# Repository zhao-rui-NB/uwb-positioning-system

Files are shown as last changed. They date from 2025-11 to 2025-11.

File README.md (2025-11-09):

# uwb-positioning-system

## 專案總覽
這個儀專案整合了 **ESP32+DWM1000 韌體**、**對應硬體設計** 與 **Python 可視化 Host App**，目標是建置可以在室內部署的 UWB 定位系統。韌體負責超寬頻量測與序列埠通訊、硬體提供可量產的電路與機構、Host App 則把距離資料轉為即時 2D/3D 位置並提供後續交接時最重要的溝通介面。

## 目錄導覽
- `firmware/`：PlatformIO 專案，產生可燒錄到 ESP32-DWM1000 節點的韌體。
- `hardware/`：ESP32_DWM1000_V1 的 PCB、BOM、殼體與 3D 檔案。
- `host_app/`：Python + PyQt6 介面，透過序列埠操控節點、做距離採樣與定位演算法。

---

## Firmware（`firmware/ESP32-DWM1000`）
1. **建置環境**
   - 安裝 [PlatformIO CLI](https://platformio.org/) 或 VS Code + PlatformIO IDE。
   - 需要 ESP32 USB 驅動與 115200 bps 序列埠。
2. **編譯與燒錄**
   - `cd firmware/ESP32-DWM1000`
   - 編譯：`pio run`
   - 燒錄：`pio run -t upload`（可用 `-t monitor` 觀察訊息）
3. **節點角色**
   - `uwb_node_id` 由程式內部邏輯或使用者命令設定，Anchor 建議使用 `0xFF00` 起跳，Tag 使用 `0x0000` 起跳。
4. **主控指令**
   - 序列埠接受 ASCII 指令，換行分隔：
     - `ping <node_id>`：請 <node_id> 回報系統狀態與電壓。
     - `trigger <initiator_id> <responder_id>`：觸發 initiator 與 responder 間的 TWR 量測。
   - 回傳為單行 JSON，事件種類：
     - `{"event":"ping_resp","node_id":...,"system_state":...,"voltage_mv":...}`
     - `{"event":"range_report","node_a_id":...,"node_b_id":...,"distance_m":...,"rssi_dbm":...}`
     - `{"event":"range_final", ...}`（最終距離結果）。

---

## Hardware（`hardware/esp32_DWM1000_V1`）
1. **PCB 製造**
   - `pcb/Gerber_esp32_DWM1000_V1_2025-10-20.zip` 交給板廠即可生產。
   - `pcb/BOM_esp32_DWM1000_*.xlsx` 提供物料代號與封裝，搭配 `InteractiveBOM_*.html` 可快速查料。
   - `pcb/SCH_Schematic1_*.pdf` 與 `3D_*.step` 提供電路與 3D 參考。
2. **外殼/治具**
   - `shell/外殼.stl`、`shell/ESP32_DWM1000_外殼2 v26.f3z` 可 3D 列印或交由 Fusion 360 編修。
   - `shell/側按鍵*.stl` 與 `shell/壓克力.dxf` 用於按鍵、壓克力面板。

---

## Host App（`host_app/`）
Host App，負責和裝置溝通、資料視覺化與定位演算。

### 環境設定
1. 使用 Python 3.11（建議建立虛擬環境 `python -m venv venv` 並啟用）。
2. 安裝套件：`pip install -r requirements.txt`。
3. 依需求編輯 `config.json`：
   - `anchors`: `id`（與韌體相同的 16-bit ID）、`pos`（[x,y,z]，單位公尺）、`enable`。
   - `tags`: `id` 與 `z`、`enable`。Z 可固定高度以減化三角定位。

### 執行與操作
1. `python UWB_DEMO_APP.py` 開啟 PyQt6 介面。
2. 於左下輸入序列埠（例如 `COM7`）與鮑率（預設 115200），按「Connect」即可建立 `SerialWorker` 執行緒。
3. 程式啟動時計時器每 `update_position` 週期會：
   - 讀取 `config.json` 中啟用的 Tag、Anchor 列表。
   - 透過 `UWBController.trigger_multiple(tag_id, anchor_ids)` 走訪所有 anchor。
   - 每次 `trigger` 會送出 `trigger <tag> <anchor>`，等待 JSON 的 `range_report/range_final`。
   - 同時可使用 `ping_single`/`ping_all` 按鈕，送出 `ping <node>` 取得電壓與狀態。
4. `TrilaterationSolver3D` 會把有效距離組合轉為 (x,y,z)，再由 `UWBKalmanFilter` 平滑並顯示在平面圖與 RSSI 表格。
5. 介面支援：
   - 拖曳 Anchor 位置（`DraggableScatterPlotItem`），並可儲存為新的 `config.json`。
   - 清除 Tag 路徑、顯示即時 RSSI/距離列表、手動載入/儲存多組配置。

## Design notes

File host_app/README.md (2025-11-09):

# Host App 指南

## 檔案對照
| 檔案 | 功能摘要 |
| --- | --- |
| `SerialWorker.py` | 底層串列通訊執行緒，維持 `Serial` 連線、將裝置回傳的 JSON 事件塞入 queue，並提供 `send_command`/`read_response` API。 |
| `UWBController.py` | 封裝序列指令集合，包含 `ping`、`trigger`、`trigger_multiple` 等方法，並以資料類別 (`RangeResponse`, `PingResponse`) 回傳解析後結果。 |
| `TrilaterationSolver3D.py` | 以多個 Anchor 座標與距離解三點/多點定位的演算法，支援固定 Z 的 3D 求解並提供校正/排序工具。 |
| `UWBKalmanFilter.py` | 對定位結果進行單點 Kalman 濾波，降低量測噪訊與跳動。每個 Tag 會各自維持一個濾波器實例。 |
| `UWB_DEMO_APP.py` | PyQt6 主程式：控制介面、Anchor/Tag 管理、即時圖表、RSSI 表格、手動載入/儲存 `config.json`，並定期呼叫控制器量測距離。 |
| `config.json` | Anchor 與 Tag 的 ID、座標、啟用狀態與預設高度設定，GUI 讀取後即能還原場地配置。拖曳 Anchor 或儲存設定時也會覆寫這個檔案。 |
| `requirements.txt` | Host App 依賴的 Python 套件列表 (PyQt6、pyserial、pyqtgraph、numpy…)，交接時可直接 `pip install -r requirements.txt`。 |

# 🛰️ UWB 定位系統上位機 (PyQt6)

## 📋 系統概述
這是一個使用 **PyQt6 + pyqtgraph** 開發的上位機應用程式，用於顯示與控制 **UWB（超寬頻）定位系統**。  
支援多個 Anchor（基站）與 Tag（標籤）節點，能透過串口通訊進行距離量測、定位與地圖可視化操作。

---

## ⚙️ 功能總覽

### 🔌 串口連線控制
- 指定連線埠 (`COM`) 與鮑率 (`Baudrate`)。
- 支援：
  - **Connect**：連線到指定序列埠。
  - **Disconnect**：中斷連線。
  - **Ping**：測試節點電壓與回應狀態。

---

### 💾 設定管理（Save / Load）
- 可儲存與載入 **Anchor** 和 **Tag** 配置：
  - `Save`：儲存目前配置為 `config.json`。
  - `Load`：從檔案中載入設定。
- 啟動時自動讀取 `config.json`（若存在）。
- 設定檔內容包括：
  - Anchor ID、座標 (X/Y/Z)、啟用狀態。
  - Tag ID、高度 Z、啟用狀態。

---

### 📍 Anchor 管理
- 新增 / 移除 Anchor 節點。
- 可編輯每個 Anchor 的：
  - ID（16 進位顯示，如 `0xFF00`）
  - 座標 X / Y / Z。
- 支援啟用 / 停用。
- 可在地圖上**拖曳** Anchor 點直接修改位置（即時更新表格）。

---

### 🎯 Tag 管理
- 新增 / 移除 Tag。
- 可設定：
  - Tag ID。
  - 固定高度 Z。
- 支援啟用 / 停用。
- 顯示：
  - Tag 即時位置。
  - 移動軌跡（含濾波平滑）。

---

### 📶 RSSI 與距離顯示
- 以表格顯示：
  - Tag ID。
  - Anchor ID。
  - 距離 (m)。
  - RSSI (dBm)。
- 定期更新，顯示最新量測結果。

---

### 🔧 Anchor 自動校正 (Calibration)
- 啟用兩個以上的 Anchor 可進行自動校正。
- 自動測距所有 Anchor 配對。
- 使用 **多維尺度分析 (MDS)** 計算相對位置。
- 自動更新 Anchor 座標與地圖。
- 僅支持2D校正（Z軸固定,需將Anchor放置於同一平面）。

---

### 🗺️ 地圖繪製與互動
- 即時顯示：
  - Anchor（紅色三角形）。
  - Tag（彩色圓點）。
  - Tag 移動路徑。
- 使用 **pyqtgraph**：
  - 鎖定等比例座標。
  - 顯示格線與軸標籤 (X/Y)。
  - Anchor 點可拖曳以修改位置。

---

### 🧹 其他輔助功能
- `Clear Paths`：清除所有 Tag 的歷史軌跡。
- 狀態列顯示系統狀態、連線資訊與錯誤提示。
- 自動檢查 Anchor 數量不足時顯示警告。

---

## 🖥️ 操作介面說明
- 左側控制面板：
  - 系統控制、連線設定、Ping 測試、Anchor/Tag 管理、RSSI 監控與校正。
- 右側地圖區：
  - 即時顯示 Anchor、Tag、軌跡。
  - 可互動拖曳 Anchor 點設定座標。

---

## 🚀 執行方式

```bash
# 建立虛擬環境
python -m venv venv
source venv/bin/activate     # (Windows 用 venv\Scripts\activate)

# 安裝依賴
pip install -r requirements.txt

# 執行主程式
python UWB_DEMO_APP.py
```

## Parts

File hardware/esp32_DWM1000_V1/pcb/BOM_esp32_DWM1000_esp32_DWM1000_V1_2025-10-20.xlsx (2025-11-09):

No. | Quantity | Comment | Designator | Footprint | Value | Manufacturer Part | Manufacturer | Supplier Part | Supplier
1 | 2 | 1uF | C1,C2 | C0805 | 1uF
2 | 9 | 0.1uF | C3,C4,C5,C6,C7,C8,C13,C14,C15 | C0805 | 0.1uF
3 | 4 | 10uF | C9,C10,C11,C12 | C0805 | 10uF
4 | 1 | X6511FRS-04-C85D30 | CN1 | HDR-SMD_4P-P2.54-H-F |  | X6511FRS-04-C85D30 | XKB Connection(中国星坤) | C5142237 | LCSC
5 | 1 | MBR230LSFT1G | D1 | SOD-123FL_L2.7-W1.8-LS3.8-RD |  | MBR230LSFT1G | onsemi(安森美) | C126673 | LCSC
6 | 1 | WAFER-PH2.0-2PWB | H1 | CONN-SMD_2P-P2.00_XUNPU_WAFER-PH2.0-2PWB |  | WAFER-PH2.0-2PWB | XUNPU(讯普) | C3029440 | LCSC
7 | 2 | LED_0805-R | LED1,LED2 | LED0805-RD_GREEN
8 | 2 | S8050 | Q1,Q2 | SOT-23-3_L2.9-W1.3-P1.90-LS2.4-BR |  | S8050 |  | C139514 | LCSC
9 | 1 | AO3401 | Q3 | SOT-23-3_L2.9-W1.6-P1.90-LS2.8-BR |  | AO3401 | BLUE ROCKET(蓝箭) | C305433 | LCSC
10 | 5 | 10k | R1,R2,R5,R8,R9 | R0805 | 10k | SCR0805F10K | VO(翔胜) |  | LCSC
11 | 6 | 10k | R3,R4,R14,R16,R17,R18 | R0805 | 10k
12 | 1 | NC | R6 | R0805 | NC | SCR0805F10K | VO(翔胜) |  | LCSC
13 | 2 | 4.7k | R7,R11 | R0805 | 4.7k | SCR0805F10K | VO(翔胜) |  | LCSC
14 | 1 | 15k | R10 | R0805 | 15k | SCR0805F10K | VO(翔胜) |  | LCSC
15 | 1 | 240k | R12 | R0805 | 240k | SCR0805F10K | VO(翔胜) |  | LCSC
16 | 4 | 1k | R13,R15,R19,R23 | R0805 | 1k | SCR0805F10K | VO(翔胜) |  | LCSC
17 | 2 | 5.1k | R20,R21 | R0805 | 5.1k | SCR0805F10K | VO(翔胜) |  | LCSC
18 | 2 | 100k | R22,R25 | R0805 | 100k | SCR0805F10K | VO(翔胜) |  | LCSC
19 | 1 | 200k | R24 | R0805 | 200k | SCR0805F10K | VO(翔胜) |  | LCSC
20 | 4 | Screw-Hole-M3 | SCREW1,SCREW2,SCREW3,SCREW4 | Screw-Hole-M3
21 | 2 | HX-3x6x2.5-X SMD tact Switch | SW1,SW2 | SW-SMD_HX-3X6X2.5-X |  | HX-3x6x2.5-X SMD tact Switch | hanxia(韩下) | C49234125 | LCSC
22 | 3 | HX-3x6x3.5-CA-0.6-2.5N | SW3,SW4,SW5 | SW-SMD_HX-3X6X3.5-CA-0.6-2.5N |  | HX-3x6x3.5-CA-0.6-2.5N | hanxia(韩下) | C49234146 | LCSC
23 | 1 | MK-12C02-G020 | SW6 | SW-SMD_MK-12C02-G020 |  | MK-12C02-G020 | G-Switch(品赞) | C963206 | LCSC
24 | 1 | DWM1000 | U1 | WIRELM-TH_DWM1000 |  | DWM1000 | decaWave | C95238 | LCSC
25 | 1 | ESP32-WROOM-32-N4 | U2 | WIFIM-SMD_ESP32-WROOM-32-N4 |  | ESP32-WROOM-32-N4 | ESPRESSIF(乐鑫) | C82899 | LCSC
26 | 2 | X6511FRS-02-C85D30 | U3,U5 | HDR-SMD_2P-P2.54-H-F-L11.5 |  | X6511FRS-02-C85D30 | XKB Connection(中国星坤) | C5142235 | LCSC
27 | 1 | CH340C | U4 | SOP-16_L10.0-W3.9-P1.27-LS6.0-BL |  | CH340C | WCH(南京沁恒) | C84681 | LCSC
28 | 1 | SGM4056-6.8YPS8G/TR | U6 | SOIC-8_L4.9-W3.9-P1.27-LS6.0-BL-EP |  | SGM4056-6.8YPS8G/TR | SGMICRO(圣邦微) | C79687 | LCSC
29 | 1 | ME6217C33M5G | U7 | SOT-23-5_L3.0-W1.7-P0.95-LS2.8-BR |  | ME6217C33M5G | MICRONE(南京微盟) | C427602 | LCSC
30 | 1 | TYPEC-304-ACP16 | USB1 | USB-C-SMD_TYPE-C-16P-1 |  | TYPEC-304-ACP16 | XUNPU(讯普) | C2982555 | LCSC

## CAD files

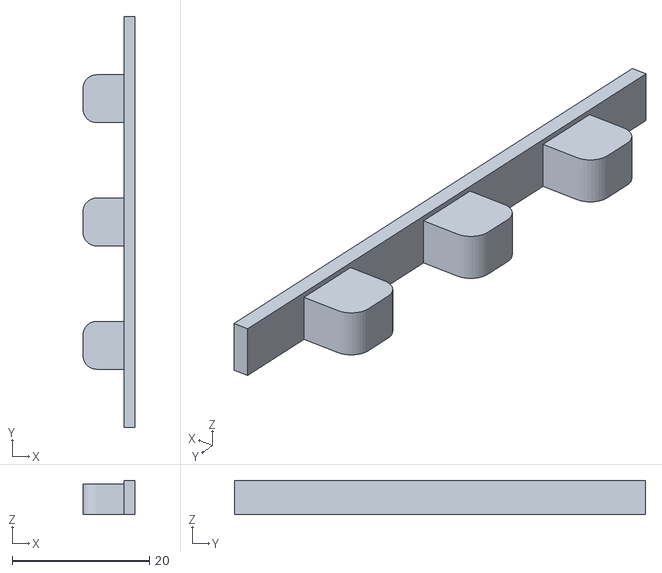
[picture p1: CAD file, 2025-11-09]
hardware/esp32_DWM1000_V1/shell/側按鍵.stl
7.60 x 60.0 x 5.00

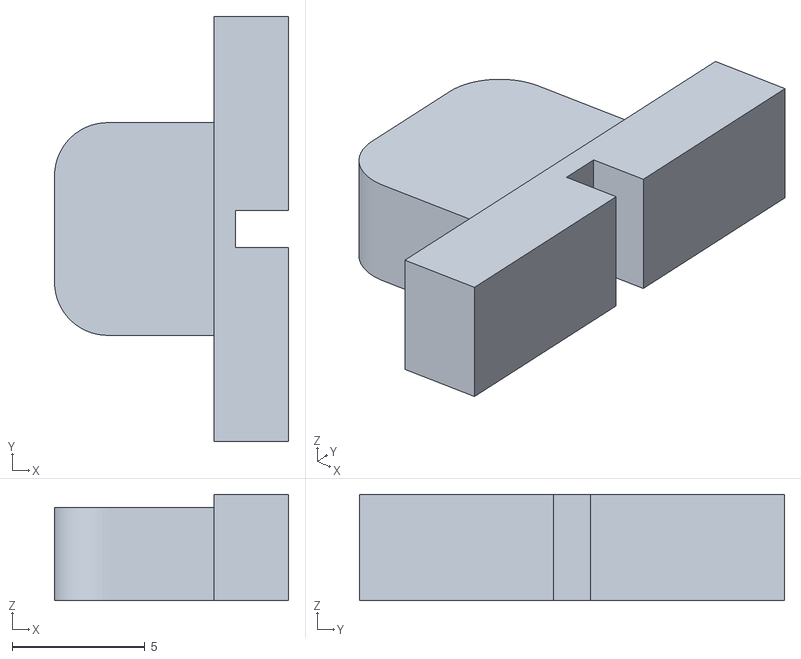
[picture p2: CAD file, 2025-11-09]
hardware/esp32_DWM1000_V1/shell/側開關.stl
8.80 x 16.0 x 4.00

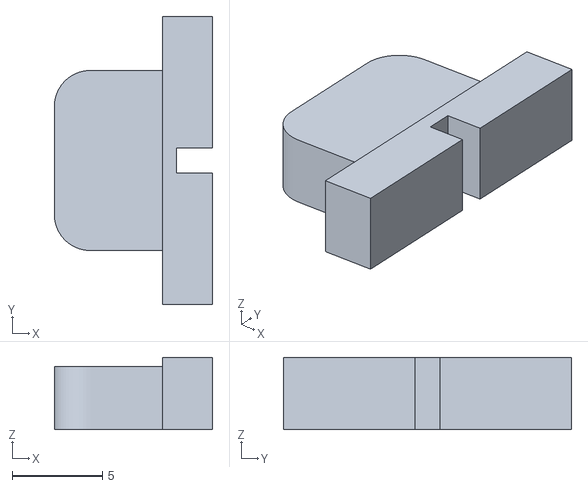
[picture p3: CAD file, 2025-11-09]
hardware/esp32_DWM1000_V1/shell/側開關V2.stl
8.80 x 16.0 x 4.00

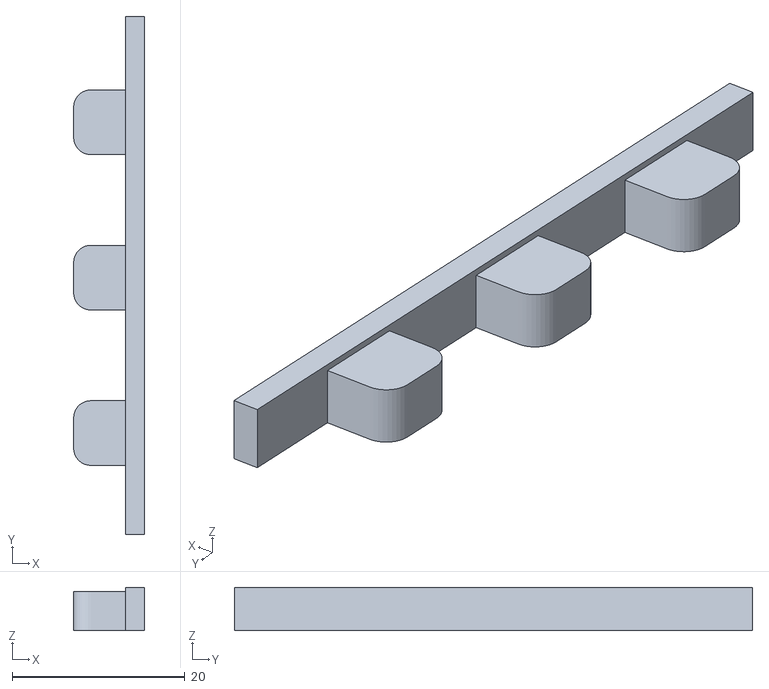
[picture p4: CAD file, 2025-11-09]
hardware/esp32_DWM1000_V1/shell/側按鍵V2.stl
8.20 x 60.0 x 5.00

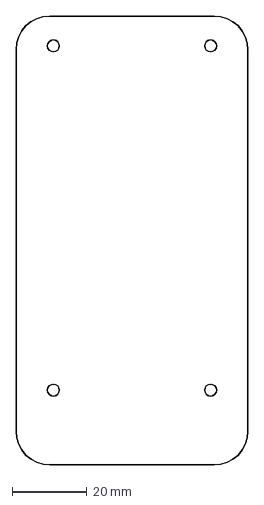
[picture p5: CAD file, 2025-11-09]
hardware/esp32_DWM1000_V1/shell/壓克力.dxf
62.0 x 120.0 mm

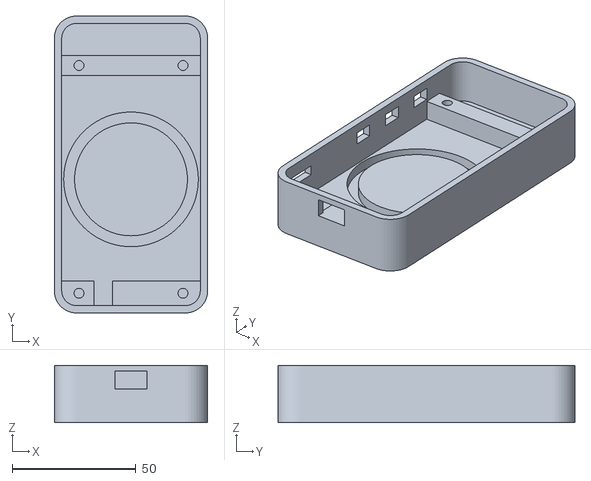
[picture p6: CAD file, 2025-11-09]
hardware/esp32_DWM1000_V1/shell/外殼.stl
62.0 x 120.0 x 23.2

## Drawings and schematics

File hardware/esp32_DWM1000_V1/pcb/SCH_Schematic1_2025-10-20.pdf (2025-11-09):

# DWM1000

ESP32 | 下載電路

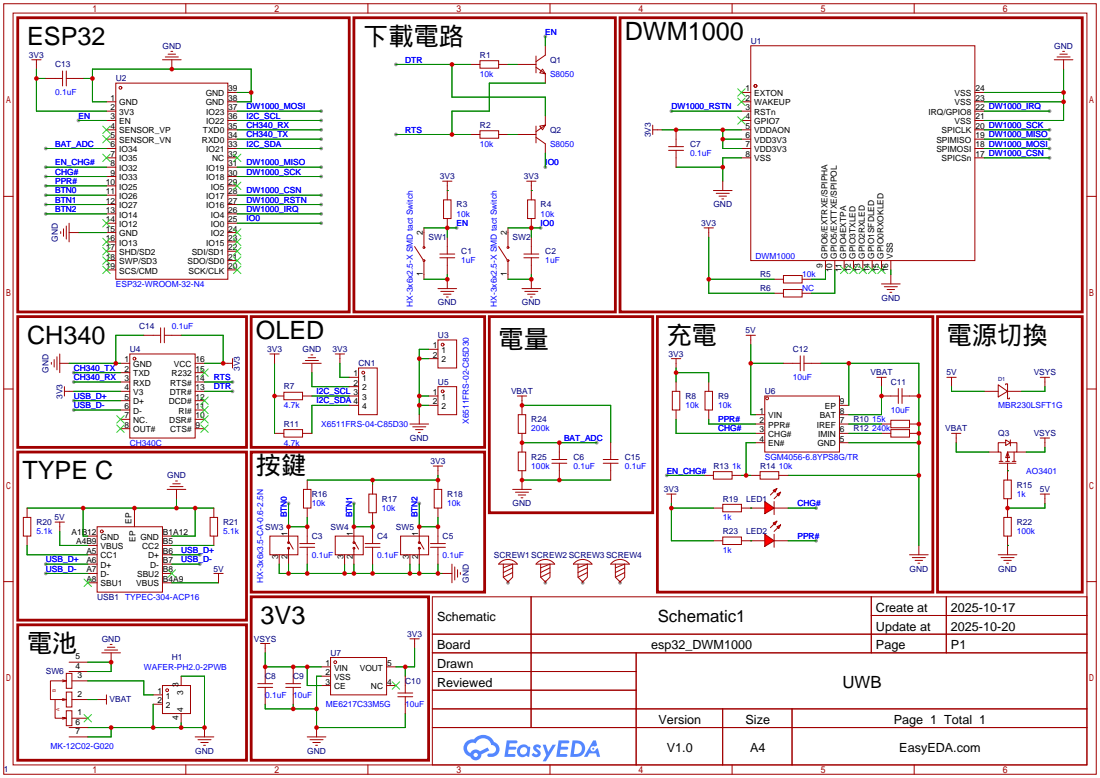
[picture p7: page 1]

SPICSn 17 SPIMOSI 18 SPIMISO 19 SPICLK 20 VSS 21 IRQ/GPIO8 22 VSS 23 VSS 24

HX-3x6x2.5-X SMD tact Switch

DSR# 10 RI# 11 DCD# 12 DTR# 13 RTS# 14 R232 15 VCC 16

Schematic | Schematic1 | Create at | 2025-10-17

Update at | 2025-10-20

Board | esp32_DWM1000 | Page | P1
Drawn | | UWB
Reviewed

Version | Size | Page 1 Total 1
V1.0 | A4 | EasyEDA.com

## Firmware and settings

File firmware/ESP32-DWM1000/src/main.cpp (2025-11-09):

#include <Arduino.h>

#include "uwb.h"

// UI
#include "HAL_Button.h"
#include "display/dispDriver.h"
#include "core/ui.h"
#include "ui_conf.h"
#include "power.h"

#include "safe_print.h"
#include "system_config.h"



ui_t ui;
int Wave_TestData;

// int int_val = 0;
// float float_val = 0.0;
// bool switch_val = false;
// char string_val[32] = "Hello MiaoUI!";
extern int int_val;
extern float float_val;
extern bool switch_val;
extern char string_val[32];

uint8_t new_event_flag = false;
uwb_event_t event_type;
uint8_t event_data[128];


void uwb_event_callback(uwb_event_t event, void *data) {
    new_event_flag = true;
    event_type = event;
}

#include "freertos/FreeRTOS.h"
#include "freertos/task.h"
#include "esp_freertos_hooks.h"
#include "freertos/task.h"
#include "freertos/FreeRTOS.h"
#include "freertos/task.h"

// add print the ui fps
void ui_task(void *param) {
    // static unsigned long last_time = 0;
    // static int frame_count = 0;
    while (1) {
        // frame_count++;
        // if (millis() - last_time >= 1000) {
        //     Serial.printf("[UI] FPS: %d\n", frame_count);
        //     frame_count = 0;
        //     last_time = millis();
        // }
        ui_loop(&ui);
        vTaskDelay(pdMS_TO_TICKS(10));
    }
}

void setup() {


    Serial.begin(115200);
    // Serial.begin(2000000);
    uint64_t chipid64 = ESP.getEfuseMac();
    Serial.printf("[esp32] ESP32 Chip ID: %08X%08X\n", (uint32_t)(chipid64>>32), (uint32_t)chipid64);
    uint32_t chipid = (uint32_t)(chipid64>>32);

    system_config_init();

    pinMode(BTN_UP, INPUT_PULLUP);
    pinMode(BTN_DOWN, INPUT_PULLUP);
    pinMode(BTN_OK, INPUT_PULLUP);

    dispInit();
    MiaoUi_Setup(&ui);


    // uwb_init();
    uwb_task_init(); // UWB irq中斷觸發 UWB 任務

    uwb_register_event_callback(uwb_event_callback);

    // chip id to select role
    // uwb_group_id = 0x1234;
    // uwb_node_id = 0x0001;
    // Serial.printf("[role] setting group_id: 0x%04X, node_id: 0x%04X\n", uwb_group_id, uwb_node_id);
    
    /*
    set_uwb_group_id(0x1234);
    
    switch(chipid) {
        case 0xCCFD:
            set_uwb_node_id(0x0001);
            Serial.printf("[role] setting group_id: 0x%04X, node_id: 0x%04X\n", get_uwb_group_id(), get_uwb_node_id());
            break;

        case 0xE406:
            set_uwb_node_id(0xFF01);
            Serial.printf("[role] setting group_id: 0x%04X, node_id: 0x%04X\n", get_uwb_group_id(), get_uwb_node_id());
            break;

        // anchor
        case 0xDC74:
            set_uwb_node_id(0xFF03);
            Serial.printf("[role] setting group_id: 0x%04X, node_id: 0x%04X\n", get_uwb_group_id(), get_uwb_node_id());
            break;
        //tag
        case 0x0C00:
            set_uwb_node_id(0x0003);
            Serial.printf("[role] setting group_id: 0x%04X, node_id: 0x%04X\n", get_uwb_group_id(), get_uwb_node_id());
            break;

        default:
            Serial.println("[ERROR] chip id does not match any role");
            set_uwb_node_id(0x0000);
            Serial.printf("[role] setting group_id: 0x%04X, node_id: 0x%04X\n", get_uwb_group_id(), get_uwb_node_id());

            // while(1) {}
    }
    */
    
    
    
    
    power_init();

    safe_print_init();

    xTaskCreatePinnedToCore(
        ui_task,          /* Task function. */
        "ui_task",        /* name of task. */
        4096,             /* Stack size of task */
        NULL,             /* parameter of the task */
        1,                /* priority of the task */
        NULL,             /* Task handle to keep track of created task */
        0);               /* pin task to core 0 */
}





void loop() {
    // delay
    vTaskDelay(pdMS_TO_TICKS(10));

    // ui_loop(&ui);

    // uwb_process();
    // uwb_process_polling_irq();

    static unsigned long last_print_ping_resp = 0;
    static unsigned long last_print_range_final = 0;
    static unsigned long last_print_range_report = 0;

    if (ping_resp_ts != last_print_ping_resp) {
        last_print_ping_resp = ping_resp_ts;
        // Serial.printf("Ping Resp Received: Node ID: 0x%04X, System State: 0x%02X, Voltage: %d mV\n",
        //     ping_resp_node_id,
        //     ping_resp_system_state, 
        //     ping_resp_voltage_mv
        // );
    
        // print as JSON format for easy parsing
        Serial.printf("{\"event\":\"ping_resp\",\"node_id\":%d,\"system_state\":%d,\"voltage_mv\":%d}\n",
            ping_resp_node_id,
            ping_resp_system_state, 
            ping_resp_voltage_mv
        );
    }

    if (range_final_ts != last_print_range_final) {
        last_print_range_final = range_final_ts;
        // Serial.printf("Range Final Received: Node A ID: 0x%04X, Node B ID: 0x%04X, Distance: %.2f m\n",
        //     range_final_node_a_id,
        //     range_final_node_b_id,
        //     range_final_distance_m
        // );
    
        Serial.printf("{\"event\":\"range_final\",\"node_a_id\":%d,\"node_b_id\":%d,\"distance_m\":%.2f,\"rssi_dbm\":%.2f}\n",
            range_final_node_a_id,
            range_final_node_b_id,
            range_final_distance_m,
            range_final_rssi_dbm
        );
    }

    if (range_report_ts != last_print_range_report) {
        last_print_range_report = range_report_ts;
        // Serial.printf("Range Report Received: Node A ID: 0x%04X, Node B ID: 0x%04X, Distance: %.2f m, RSSI: %.2f dBm\n",
        //     range_report_node_a_id,
        //     range_report_node_b_id,
        //     range_report_distance_m,
        //     range_report_rssi_dbm
        // );
    
        // print as JSON format for easy parsing
        Serial.printf("{\"event\":\"range_report\",\"node_a_id\":%d,\"node_b_id\":%d,\"distance_m\":%.2f,\"rssi_dbm\":%.2f}\n",
            range_report_node_a_id,
            range_report_node_b_id,
            range_report_distance_m,
            range_report_rssi_dbm
        );
    }





    // handle UWB events
    if (new_event_flag) {
        new_event_flag = false;
        // // print event for debugging
        // switch (event_type) {
        //     case UWB_EVENT_PING_RESP_TIMEOUT:       Serial.printf("[UWB EVENT FLAG] PING RESP timeout\n");         break;
        //     case UWB_EVENT_RANGE_RESP_TIMEOUT:      Serial.printf("[UWB EVENT FLAG] RANGE RESP timeout\n");         break;
        //     case UWB_EVENT_RANGE_FINAL_TIMEOUT:     Serial.printf("[UWB EVENT FLAG] RANGE FINAL timeout\n");        break;
        //     case UWB_EVENT_RANGE_REPORT_TIMEOUT:    Serial.printf("[UWB EVENT FLAG] RANGE REPORT timeout\n");       break;
        //     case UWB_EVENT_UNKNOWN_FRAME_TIMEOUT:   Serial.printf("[UWB EVENT FLAG] UNKNOWN FRAME timeout\n");      break;
        //     case UWB_EVENT_UNKNOWN_FRAME_ERROR:     Serial.printf("[UWB EVENT FLAG] UNKNOWN FRAME error\n");        break;
        //     case UWB_EVENT_INVALID_FRAME_RECEIVED:  Serial.printf("[UWB EVENT FLAG] INVALID FRAME received\n");     break;
        // }
    }

    // parse uart commands 
    // cmd1: ping <node_id>
    // cmd2: trigger <node_id> <range_node_id>
    // cmd3: range <range_node_id>
    
    if (Serial.available()) {
        String line = Serial.readStringUntil('\n');
        line.trim();
        if (line.length() == 0) {
            return;
        }

        // Serial.printf("Received command: %s\n", line.c_str());

        char cmd[32];
        char arg1[32];
        char arg2[32];

        int num_args = sscanf(line.c_str(), "%31s %31s %31s", cmd, arg1, arg2);

        if (strcmp(cmd, "ping") == 0 && num_args == 2) {
            uint16_t target_node_id = strtol(arg1, NULL, 0);
            uint8_t succ = uwb_send_ping_req(target_node_id);
        }
        else if (strcmp(cmd, "trigger") == 0 && num_args == 3) {
            uint16_t initiator_id = strtol(arg1, NULL, 0);
            uint16_t responder_id = strtol(arg2, NULL, 0);
            uint8_t succ = uwb_send_range_trigger(initiator_id, responder_id);
        }
        else {
            Serial.println("Unknown command or wrong number of arguments");
        }

    }

}

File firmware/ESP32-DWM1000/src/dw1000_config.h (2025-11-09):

#ifndef __DW1000_CONFIG_H__
#define __DW1000_CONFIG_H__

#include "dw1000.h"
#include "deca_device_api.h"
#include "deca_regs.h"

// static dwt_config_t config = {
//     2,               /* Channel number. */
//     DWT_PRF_64M,     /* Pulse repetition frequency. */
//     DWT_PLEN_1024,   /* Preamble length. Used in TX only. */
//     DWT_PAC64,       /* Preamble acquisition chunk size. Used in RX only. */
//     10,               /* TX preamble code. Used in TX only. */
//     10,               /* RX preamble code. Used in RX only. */
//     1,               /* 0 to use standard SFD, 1 to use non-standard SFD. */
//     DWT_BR_110K,     /* Data rate. */
//     DWT_PHRMODE_STD, /* PHY header mode. */
//     (1024 + 1 + 64 - 32) /* SFD timeout (preamble length + 1 + SFD length - PAC size). Used in RX only. */
// };


static dwt_config_t config = {
    2,               /* Channel number. */
    DWT_PRF_64M,     /* Pulse repetition frequency. */
    DWT_PLEN_1024,   /* Preamble length. Used in TX only. */
    DWT_PAC64,       /* Preamble acquisition chunk size. Used in RX only. */
    9,               /* TX preamble code. Used in TX only. */
    9,               /* RX preamble code. Used in RX only. */
    1,               /* 0 to use standard SFD, 1 to use non-standard SFD. */
    DWT_BR_110K,     /* Data rate. */
    DWT_PHRMODE_STD, /* PHY header mode. */
    (1024 + 1 + 64 - 32) /* SFD timeout (preamble length + 1 + SFD length - PAC size). Used in RX only. */
};

static dwt_txconfig_t txconfig = {
    0xC2,            /* PG delay. */
    0x1f1f1f1f,      /* TX power. */
};

#define RNG_DELAY_MS 100

#define ANT_DLY 16470
#define TX_ANT_DLY ANT_DLY
#define RX_ANT_DLY ANT_DLY

/* UWB microsecond (uus) to device time unit (dtu, around 15.65 ps) conversion factor.
 * 1 uus = 512 / 499.2 µs and 1 µs = 499.2 * 128 dtu. */
#define UUS_TO_DWT_TIME 65536
#define SPEED_OF_LIGHT 299702547

// #define POLL_RX_TO_RESP_TX_DLY_UUS 6000
// #define RESP_TX_TO_FINAL_RX_DLY_UUS 5000 // rx delay
// #define FINAL_RX_TIMEOUT_UUS 60000

// #define POLL_TX_TO_RESP_RX_DLY_UUS 3000 // rx delay
// #define RESP_RX_TO_FINAL_TX_DLY_UUS 10000
// #define RESP_RX_TIMEOUT_UUS 60000

#define RX_BUF_LEN 128
#define TX_BUF_LEN 128

// ### ping ###
// #define PING_RX_TIMEOUT_UUS 60000

// for int test
#define PING_RX_TIMEOUT_UUS 30000

// ### range ###
// //only polling
// #define RANGE_RESP_TX_DELAY_UUS     6000 // resp tx delay
// #define RANGE_FINAL_TX_DELAY_UUS    6000 // final tx delay

// #define RANGE_RESP_RX_TIMEOUT_UUS   30000 // resp rx timeout
// #define RANGE_FINAL_RX_TIMEOUT_UUS  30000 // final rx timeout


// int test 2000:x 3000:OK 
#define RANGE_RESP_TX_DELAY_UUS     5000 // resp tx delay
#define RANGE_FINAL_TX_DELAY_UUS    5000 // final tx delay

#define RANGE_RESP_RX_TIMEOUT_UUS   30000 // resp rx timeout
#define RANGE_FINAL_RX_TIMEOUT_UUS  30000 // final rx timeout


// //polling
// #define RANGE_RESP_TX_DELAY_UUS     60000UL // 30000 // resp tx delay
// #define RANGE_FINAL_TX_DELAY_UUS    60000UL // 30000 // final tx delay

// #define RANGE_RESP_RX_TIMEOUT_UUS   65000 // resp rx timeout
// #define RANGE_FINAL_RX_TIMEOUT_UUS  65000 // final rx timeout

#endif // __DW1000_CONFIG_H__

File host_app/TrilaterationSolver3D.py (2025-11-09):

import numpy as np

class TrilaterationSolver3D:
    """
    通用三維 / 已知 Z 的 UWB 定位求解器

    支援：
      - 3D Trilateration（未知 z，需要 ≥4 anchors）
      - 已知 Z 化簡求解（需要 ≥3 anchors）
    """

    def __init__(self, anchors):
        """
        anchors: list[tuple(float, float, float)]
            anchor 座標，例如 [(x1, y1, z1), (x2, y2, z2), ...]
        """
        self.anchors = np.array(anchors, dtype=float)
        if self.anchors.shape[1] != 3:
            raise ValueError("Anchors 必須為 3 維座標 (x, y, z)。")

    # ------------------------------------------------------------
    def solve(self, distances, known_z=None):
        """
        計算 Tag 的座標。

        參數:
            distances : list[float]
                量測距離 (m)
            known_z : float | None
                若指定已知 z，則使用 2D 簡化解

        回傳:
            np.array([x, y, z])
        """
        anchors = self.anchors
        d = np.array(distances, dtype=float)
        n = len(anchors)

        if known_z is not None:
            return self._solve_known_z(anchors, d, known_z)

        if n < 4:
            raise ValueError("3D 定位需要至少 4 個 anchors。")

        # === 3D 線性化 ===
        A = 2 * (anchors[1:] - anchors[0])
        b = (
            np.sum(anchors[1:]**2, axis=1)
            - np.sum(anchors[0]**2)
            + d[0]**2
            - d[1:]**2
        )

        # === 最小平方解 ===
        pos = np.linalg.lstsq(A, b, rcond=None)[0]
        return pos

    # ------------------------------------------------------------
    def _solve_known_z(self, anchors, d, z_tag):
        """
        已知 Z (例如 Tag 高度固定）時的 2D 化簡求解。
        """
        n = len(anchors)
        if n < 3:
            raise ValueError("已知 Z 的情況下需要至少 3 個 anchors。")

        # 修正距離: 扣除垂直高度差
        dz = z_tag - anchors[:, 2]
        d_xy = np.sqrt(np.maximum(d**2 - dz**2, 0))

        # 以第一個 anchor 為基準建立線性方程
        anchors_2d = anchors[:, :2]
        A = 2 * (anchors_2d[1:] - anchors_2d[0])
        b = (
            np.sum(anchors_2d[1:]**2, axis=1)
            - np.sum(anchors_2d[0]**2)
            + d_xy[0]**2
            - d_xy[1:]**2
        )

        pos_2d = np.linalg.lstsq(A, b, rcond=None)[0]
        return np.array([pos_2d[0], pos_2d[1], z_tag])

    # ------------------------------------------------------------
    @staticmethod
    def test_solver():
        """
        測試與驗證公式正確性。
        """
        anchors = np.array([
            [0, 0, 0],
            [1, 0, 0],
            [0, 1, 0],
            [0, 0, 1]
        ])
        true_pos = np.array([0.5, 0.5, 0.5])
        d = np.linalg.norm(anchors - true_pos, axis=1)

        solver = TrilaterationSolver3D(anchors)
        est = solver.solve(d)
        print("✅ 測試 (3D)")
        print("真實位置:", true_pos)
        print("估計結果:", np.round(est, 3))
        print("誤差:", np.linalg.norm(est - true_pos))

        # 測試已知 Z 模式
        z_known = 0.5
        est2 = solver.solve(d, known_z=z_known)
        print("\n✅ 測試 (已知 Z)")
        print("估計結果:", np.round(est2, 3))
        print("誤差:", np.linalg.norm(est2 - true_pos))







if __name__ == "__main__":
    import time
    import numpy as np
    import matplotlib.pyplot as plt
    from matplotlib.animation import FuncAnimation
    
    
    from SerialWorker import SerialWorker
    from UWBController import UWBController
    from UWBKalmanFilter import UWBKalmanFilter
    

    # === 初始化繪圖 ===
    def setup_plot(anchors):
        fig, ax = plt.subplots()
        ax.set_title("UWB 2D Positioning (Top View)")
        ax.set_xlabel("X (m)")
        ax.set_ylabel("Y (m)")
        ax.grid(True)
        ax.set_aspect('equal', 'box')

        anchors_np = np.array(anchors)
        ax.scatter(anchors_np[:, 0], anchors_np[:, 1],
                c='red', marker='^', s=100, label='Anchors')
        for i, (x, y, z) in enumerate(anchors):
            ax.text(x + 0.05, y + 0.05, f"A{i}", color='red')

        tag_dot, = ax.plot([], [], 'bo', markersize=10, label='Tag')
        path_line, = ax.plot([], [], 'b--', alpha=0.4)
        pos_text = ax.text(0.02, 0.95, "", transform=ax.transAxes)

        ax.legend()
        plt.tight_layout()

        # 儲存軌跡資料
        data = {"path_x": [], "path_y": [], "pos": [0, 0, 0]}

        # === 更新函數 ===
        def update(frame):
            x, y, z = data["pos"]
            data["path_x"].append(x)
            data["path_y"].append(y)
            if len(data["path_x"]) > 10:
                data["path_x"].pop(0)
                data["path_y"].pop(0)

            tag_dot.set_data([x], [y])
            path_line.set_data(data["path_x"], data["path_y"])
            pos_text.set_text(f"x={x:.2f}, y={y:.2f}, z={z:.2f}")
            return tag_dot, path_line, pos_text

        ani = FuncAnimation(fig, update, interval=50, blit=False, save_count=100)
        plt.show(block=False)

        return data, fig, ani

    anchor_ids = [0xFF00, 0xFF01, 0xFF02, 0xFF03]
    tag_ids = [0x0000]
    
    anchors = [
        (0, 0, 1.53),
        (-0.35, 1.12, 2.23),
        (2.57, 1.61, 2.21),
        (2.57, -0.51, 2.24)
    ]

    COM = "COM18"
    worker = SerialWorker(port=COM, baudrate=115200, debug_print=False)
    worker.open()
    uwb = UWBController(serial_worker=worker, debug_print=False)
    
    kf = UWBKalmanFilter(dt=0.2, process_var=1e-3, measurement_var=1e-1)

    # 🔹 初始化繪圖
    data, fig, ani = setup_plot(anchors)
    
    try:
        while True:
            reports = uwb.trigger_multiple(tag_ids[0], anchor_ids)
            dist_list = [r.distance_m if r else -1 for r in reports]
            rssi_list = [r.rssi_dbm if r else -1 for r in reports]
            
            solver = TrilaterationSolver3D(anchors)
            pos = solver.solve(dist_list, known_z=1.0)
            pos_filtered = kf.filter(pos)
            
            print(f"\t計算結果: [{pos[0]:.2f},{pos[1]:.2f},{pos[2]:.2f}]", end="")
            print(f"📡 Tag {tag_ids[0]}: RSSI={rssi_list}, Dist={dist_list}  ")
            
                        
            # 更新畫面用的資料
            data["pos"] = pos_filtered
            plt.pause(0.05)

            # print(f"📍[{pos[0]:.2f},{pos[1]:.2f},{pos[2]:.2f}] | RSSI={rssi_list} | Dist={dist_list}")

            
    except KeyboardInterrupt:
        print("Exiting...")

    worker.close()
